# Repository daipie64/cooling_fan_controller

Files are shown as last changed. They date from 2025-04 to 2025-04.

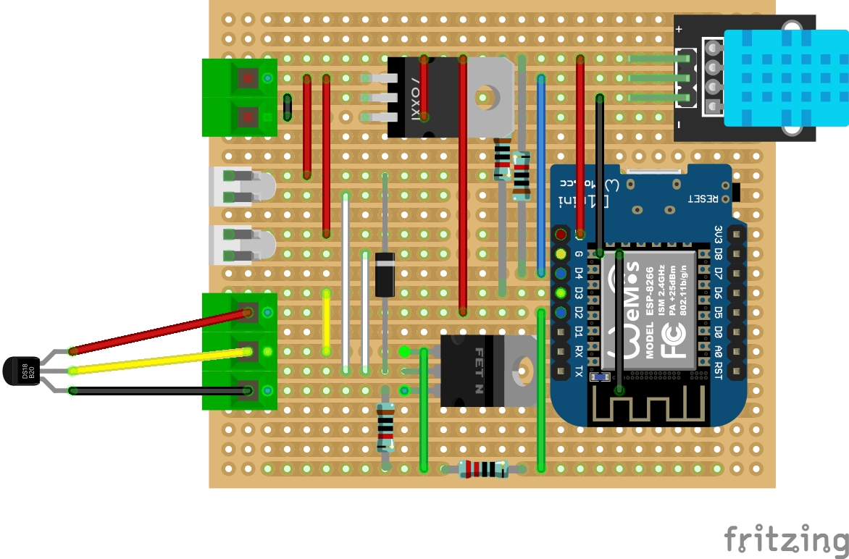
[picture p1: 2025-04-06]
Cooling Fan Controller_stripboard_layout.jpg

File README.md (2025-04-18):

# Cooling Fan Controller
Cooling fan controller for Victron Orion DC-DC Charger in Vanessa.

Based on the what I've discovered whilst prototyping:
* [Temperature Sensor Prototype](https://github.com/daipie64/Temperature-Sensor-Prototype)
* [Temperature Controlled Fan Prototype](https://github.com/daipie64/Temperature-Controlled-Fan-Prototype)

## Inspiration
[PWM Fan Project](https://www.youtube.com/watch?v=yqBcSsRsv4I&list=PLWRTMby105bi6HiwsOhd--TAUyEIyOeb6).

## Components
* ESP8266 D1 Mini
  * The MCU to control the fan and read sensors.
* 12V to 5V regulator
  * [Positive Voltage Regulator 5.5-32V to 5V1A Buck Module](https://kunkune.co.uk/shop/dc-to-dc-converters/positive-voltage-regulator-5-5-32v-to-5v1a-buck-module/)
* 12V Fan
  * These are [12V 2-wire 6cm 6015 mini fans from Ali Express](https://www.aliexpress.com/item/33019293160.html?spm=a2g0o.order_list.order_list_main.59.7a5f1802asBSGx).
  * Voltage: 12V
  * Current Rating: 0.18A +/-10%
  * Speed: 4800RPM +/-10%
  * Connector: 2pin (XH2.54)
* 1N4007 Diode
  * Flyback diode to protect against voltage spikes.
  * The fans are inductive loads so the circuit should be protected by a "flyback diode".
  * IN4007
* Dallas DS18B20
  * Measures the Victron Orion's temperature.
  * 10kΩ Resistor – Pull-up resistor for the DS18B20.
* DHT11
  * Measures ambient temperature and humidity.
  * 10kΩ Resistor – Pull-up resistor for the DHT11.
* IRLZ34N MOSFET
  * Logic level mosfet.
  * Switches the fan on and off.
  * Gate Inrush Resistor 470Ω – Limits current into the MOSFET’s gate.
  * [IRLZ34N](https://www.infineon.com/dgdl/Infineon-IRLZ34N-DataSheet-v01_01-EN.pdf?fileId=5546d462533600a40153567206892720).
  * The IRLZ34N MOSFET can be used to switch a 12V, 0.2A fan. The IRLZ34N is a logic-level MOSFET with a low gate threshold voltage, which makes it suitable for switching with a microcontroller or other low-voltage logic. It can handle much higher currents and voltages than your fan requires, so it will work well for your application.
  * Gate Discharge Resistor. A "pull-down resistor" between the gate of the MOSFET and ground is a common practice to ensure that the gate is pulled to ground when there is no active drive signal, preventing the MOSFET from turning on unintentionally due to stray voltages or noise. A typical value for this pull-down resistor is between 10k ohms and 100k ohms. This value is high enough to not interfere with the gate drive but low enough to effectively pull the gate to ground when needed. It ensures the MOSFET remains off when there is no driving signal applied, which is crucial for reliable operation.
 
## Generating the code.
I used ChatGPT to generate the code. The prompt & subsequent chat dialog can be seen here. [ChatGPT: Temp controlled fan](https://chatgpt.com/share/67d2d8a2-fc4c-8001-b3f6-e2f3b498e3e5)

After ChatGPT had created the initial code I went back to the char and asked it to generate algorithms that set fan speed update interval based on the temperaure. The idea being that when the temerature is close to ambient then the update interval does not need to be that often .... but does increase when the temperature is perhaps above optimal.

ChatGPT went on to suggest some other cool things:
* Lovelace dashboard cards to control everything visually
* Then showed me how to make these cards "conditional" - for example, hide unused sliders when a different model is selected.
* A toggle to enable/disable adaptive control
* Logging suggestions to track which model is active and how it performs
* A graph card to visualize interval & fan speed trends over time - with color-coding & advanced graph customization
* Then showed me how to install mini-graph-card and create sleek sparkline graphs with shaded thresholds
* Then a "model performance comparison" card that logs/visualizes which model was active over time

Here's the chat history for that [ChatGPT: add adaptive update algorithms plus some other cool things](https://chatgpt.com/g/g-HaRByhtTl-home-assistant-assistant/c/67d7064d-9ef4-8001-b204-753f9bf6a477)

Quite a few things didn't work with the version of ESPHome that I was running - I guess the model was for an older version. Anyway, it gave ne some great ideas and the first version adapted the speed of the fans linearly ... I may go on to look at the other algorithms - we'll see :-)

## Runtime Current Draw
I measured the following current draw.

With fans at idle the current draw was 0.03A, 0.36W.

With fans at full spped the current draw was 0.35A, 4.2W.

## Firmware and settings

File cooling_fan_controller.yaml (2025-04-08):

substitutions:
  dallas_address: "0xcd3c78e381676b28"

esphome:
  name: fan-victron-orion-dc-charger
  friendly_name: Cooling Fan for Victron Orion DC Charger

esp8266:
  board: d1_mini

# Enable logging
logger:
  level: ERROR
  logs:
    dallas.sensor: none
    number: none
    sensor: none
    light: none
    fan: none

# Enable Home Assistant API
api:
  encryption:
    key: "pD5POkoUsLKZhs7/l82lh75II3wDsQoCku6tOaoyf/U="

ota:
  - platform: esphome
    password: "dc069ead6a1cfadd028cb54c7418c0a7"

wifi:
  ssid: !secret wifi_ssid
  password: !secret wifi_password

  # Enable fallback hotspot (captive portal) in case wifi connection fails
  ap:
    ssid: "Fan-Victron-Orion-Dc-Charger"
    password: "cVZ8rJwFDoWT"

captive_portal:

number:
  # Slider to set Min Temperature to start fan
  - platform: template
    id: fan_threshold
    name: Threshold Temperature
    optimistic: True
    min_value: 20
    max_value: 60
    initial_value: 25
    step: 1
    restore_value: true # Store setting between reboots

  # # Home Assistant Slider for Temperature Update Interval
  # - platform: homeassistant
  #   entity_id: input_number.temperature_update_interval
  #   id: update_interval
  #   internal: true  # Not exposed as a sensor in ESPHome

globals:
  # track whether the fan was previously off, and give it a one-time kick when it starts
  - id: fan_started
    type: bool
    restore_value: no
    initial_value: 'false'

# update interval will be every 60 seconds whilst the fan is off,
# 2 seconds whilst we are kick starting the fan
# then 5 seconds whilst te fan is running
  - id: last_interval
    type: int
    restore_value: no
    initial_value: '60000'  # ms (60s)

# DS18B20 Temperature Sensor
one_wire:
  - platform: gpio
    # pin: D3
    pin: GPIO0

sensor:
  # Fan Speed Sensor (Reports % Speed to Home Assistant)
  - platform: template
    name: "Fan Speed"
    id: fan_speed_sensor
    unit_of_measurement: "%"
    accuracy_decimals: 0
    
  # Update Interval (Reports interval to Home Assistant)
  - platform: template
    name: "Update Interval"
    id: update_interval
    unit_of_measurement: "s"
    accuracy_decimals: 0
    
  # DHT11 Ambient Temperature Sensor
  - platform: dht
    pin: D4  # GPIO2
    model: DHT11
    temperature:
      name: "Ambient Temperature"
      id: ambient_temp
    humidity:
      name: "Ambient Humidity"
      id: ambient_humidity
    update_interval: 5s

  # Dallas DS18B20 Victron Orion DC Charger Temperature Sensor
  - platform: dallas_temp
    address: $dallas_address
    name: "Victron Charger Temp"
    id: charger_temp
    update_interval: 5s
    setup_priority: -100

    # Adjust fan speed(1-100%). Else, turn it off and set the speed to 1
    on_value:
      - lambda: |-
          float temp = id(charger_temp).state;
          float threshold = id(fan_threshold).state;
          float speed = 0.0;

          if (temp >= threshold) {
            if (!id(fan_started)) {
              // Kickstart the fan with 100% power for 2 seconds
              id(fan_pwm_output).set_level(1.0);
              id(fan_speed_sensor).publish_state(100.0);
              id(fan_started) = true;
              delay(2000);  // Wait 2 seconds before continuing
            }

            // Scale speed from 20% at threshold to 100% at 40°C
            float slope = (1.0 - 0.2) / (40.0 - threshold);
            speed = 0.2 + slope * (temp - threshold);
            if (speed > 1.0) speed = 1.0;
          } else {
            id(fan_started) = false;  // Reset flag when temp falls below threshold
          }

          id(fan_pwm_output).set_level(speed);
          id(fan_speed_sensor).publish_state(speed * 100.0);
          id(charger_temp).set_update_interval(100000);


# PWM Control via MOSFET
output:
  - platform: esp8266_pwm
    pin: D2  # GPIO4 (MOSFET Gate)
    frequency: 20kHz # 20kHz should be outside hearing range
    id: fan_pwm_output

# Fan Speed Automation (Dynamic Speed Based on Temperature)
fan:
  - platform: speed
    output: fan_pwm_output
    name: "Cooling Fan"
    id: cooling_fan

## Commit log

2025-03-17 Create cooling_fan_controller.yaml
    ChatGPTs first version
    [cooling_fan_controller.yaml]
2025-03-17 Update cooling_fan_controller.yaml
    merged in ESPHome generated code
    [cooling_fan_controller.yaml]
2025-03-17 Added EasyEDA Circuit schematic
2025-03-17 Added schematic diagram
2025-03-17 component library changes to allow PCB creation
2025-03-17 new image to match schematic
2025-03-18 Update cooling_fan_controller.yaml
    implemented basic pwm control
    [cooling_fan_controller.yaml]
2025-03-19 schematic v1.2
    This version was verified on a breadboard
2025-03-19 uploaded v1.3
    fixed diode orientation
2025-03-22 Using Fritzing for schematics and strip board layout
    [Cooling Fan Controller.fzz]
2025-03-22 Delete SCH_Victron-Orion-DC-DC-Charger-Cooling-Fan-Controller_2025-03-17.json
    Switching to fritzing
2025-03-22 Delete SCH_Victron-Orion-DC-DC-Charger-Cooling-Fan-Controller_2025-03-19.json
    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
2025-03-22 Delete Schematic_Victron-Orion-DC-DC-Charger-Cooling-Fan-Controller_2025-03-17.svg
    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
2025-03-22 Delete Schematic_Victron-Orion-DC-DC-Charger-Cooling-Fan-Controller_2025-03-19.svg
    switching to fritzing
2025-03-23 more compact stripboard layout
    [Cooling Fan Controller.fzz]
2025-03-23 adjusted code to use data pins selected during stripboard layout
    [cooling_fan_controller.yaml]
2025-03-25 final layout with jst connectors for the fans
    [Cooling Fan Controller.fzz]
2025-03-30 routing complete - compact stripboard layout
    [Cooling Fan Controller.fzz]
2025-04-06 final layout with connectors at one end
    [Cooling Fan Controller.fzz]
2025-04-06 minor relayout to accommodate extra row required between jst connectors
    [Cooling Fan Controller.fzz]
2025-04-08 Update cooling_fan_controller.yaml
    gpio as per board build
    kick start fans to get over inertia
    [cooling_fan_controller.yaml]
2025-04-18 Update README.md
    Added measured current draw figures.
